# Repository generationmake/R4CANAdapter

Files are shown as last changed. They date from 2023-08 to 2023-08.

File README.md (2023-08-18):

# R4CANAdapter
CAN adapter for the Arduino UNO R4 minima and Arduino UNO R4 WiFi

<p align="center">
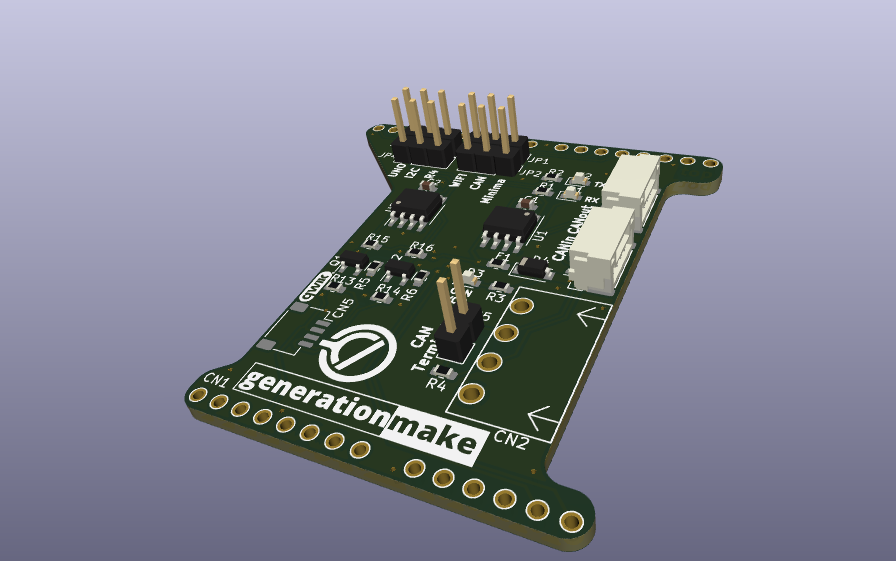
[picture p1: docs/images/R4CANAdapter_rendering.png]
  
</p>

## PCB
### Top
<p align="center">
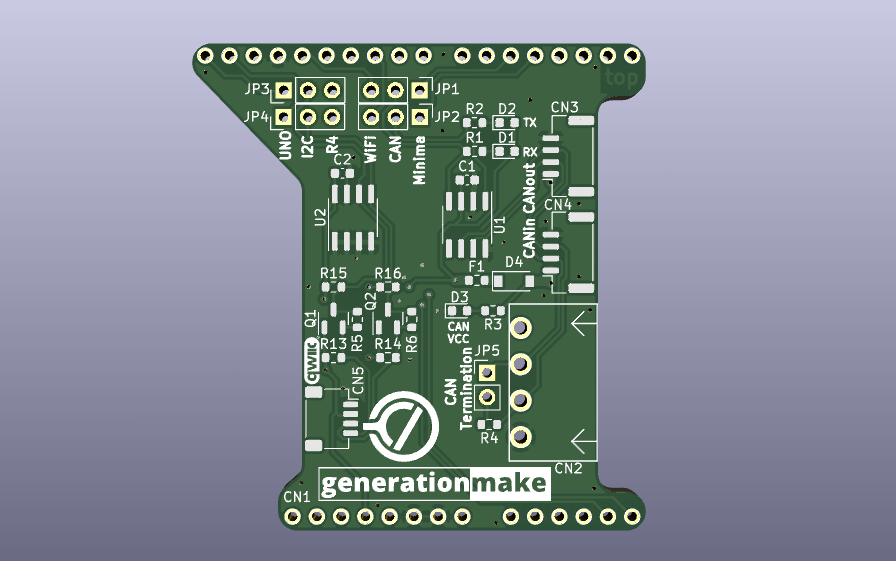
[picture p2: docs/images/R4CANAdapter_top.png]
  
</p>

### Bottom
<p align="center">
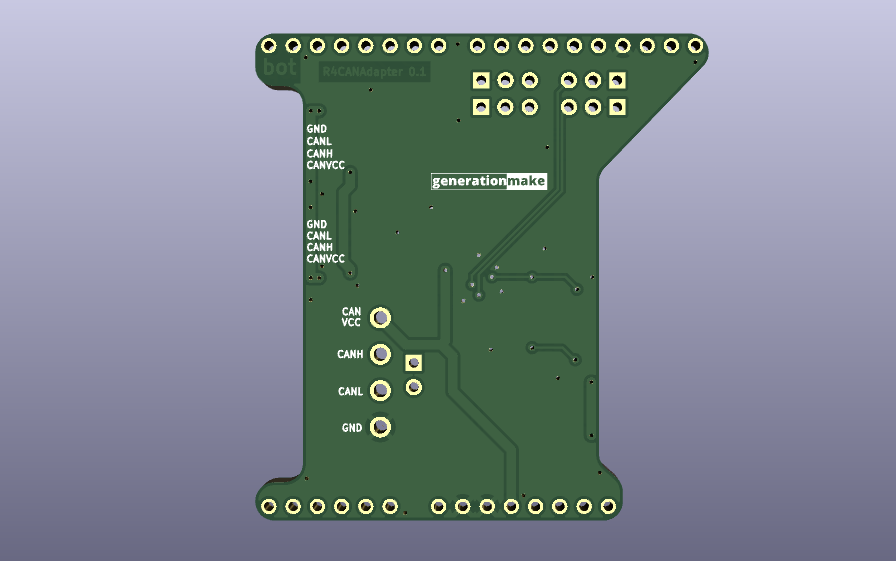
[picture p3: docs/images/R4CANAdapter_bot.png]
  
</p>

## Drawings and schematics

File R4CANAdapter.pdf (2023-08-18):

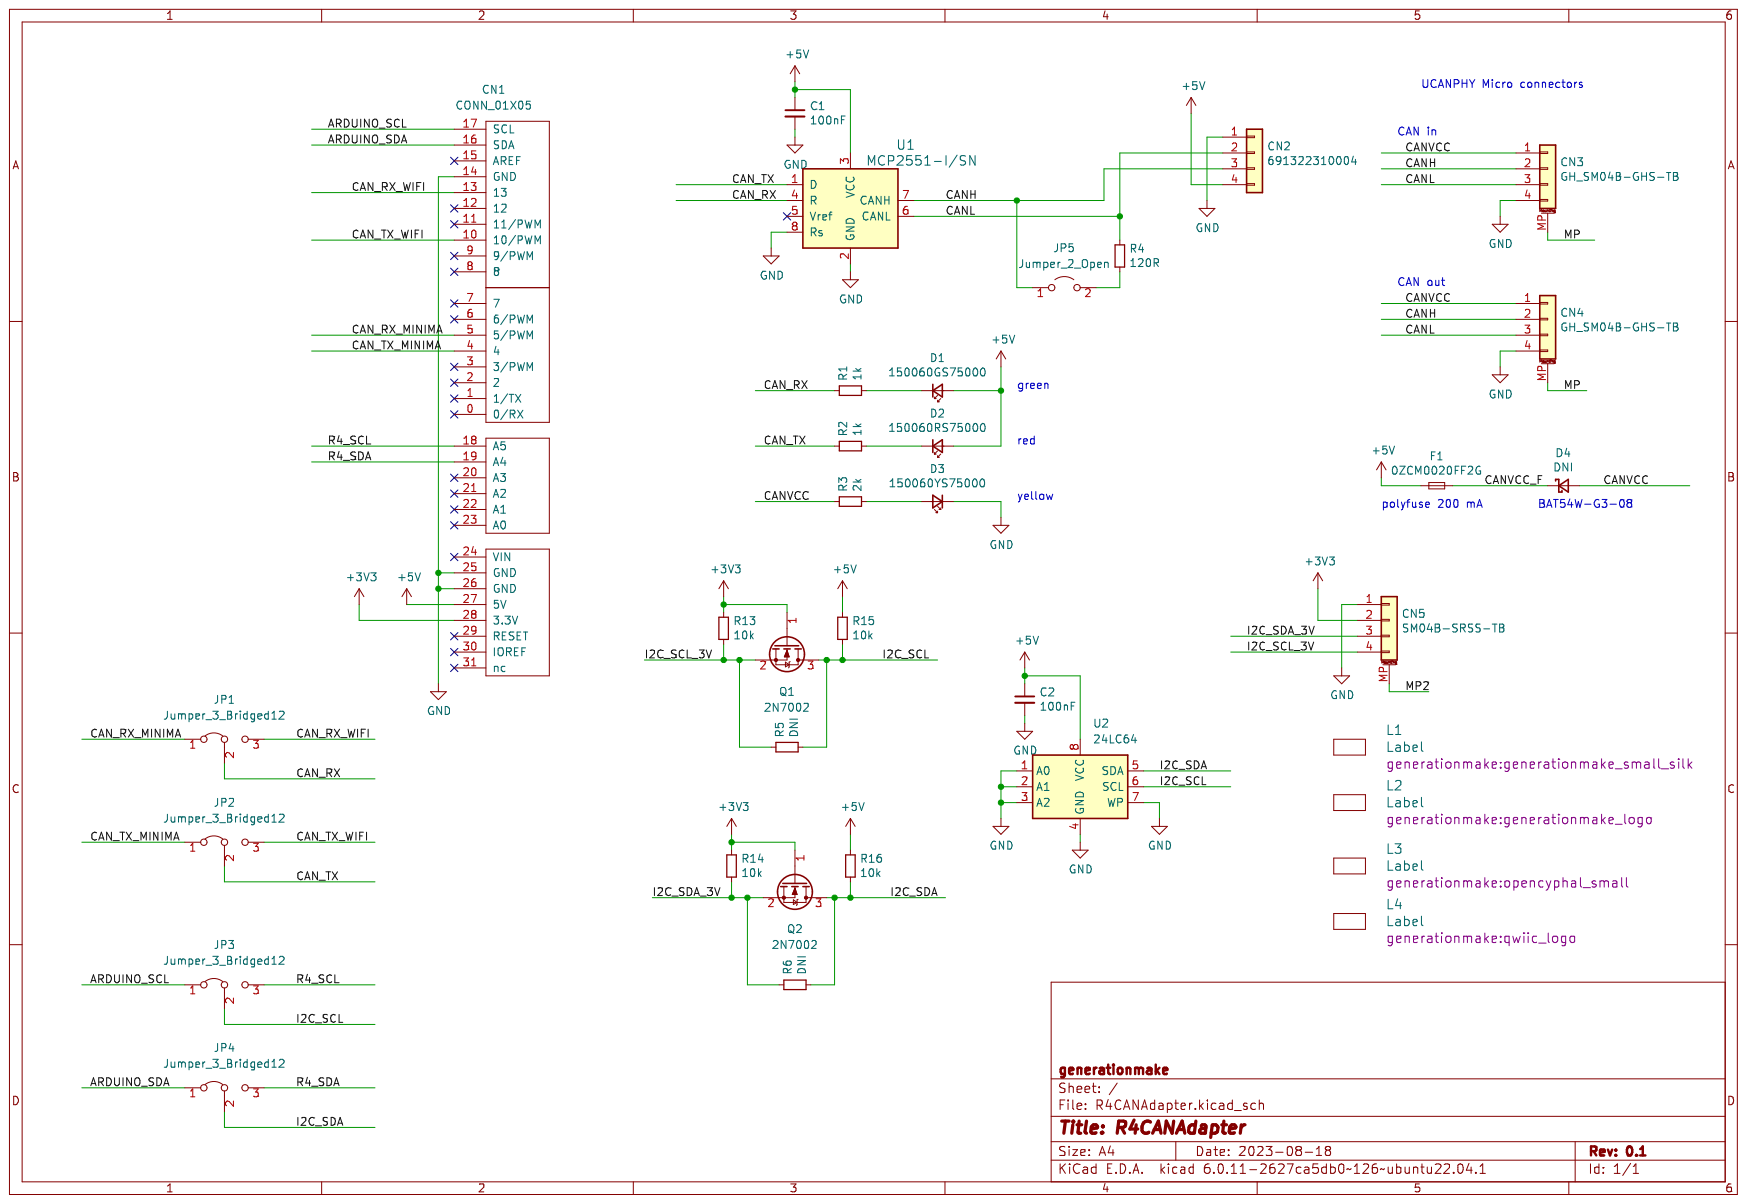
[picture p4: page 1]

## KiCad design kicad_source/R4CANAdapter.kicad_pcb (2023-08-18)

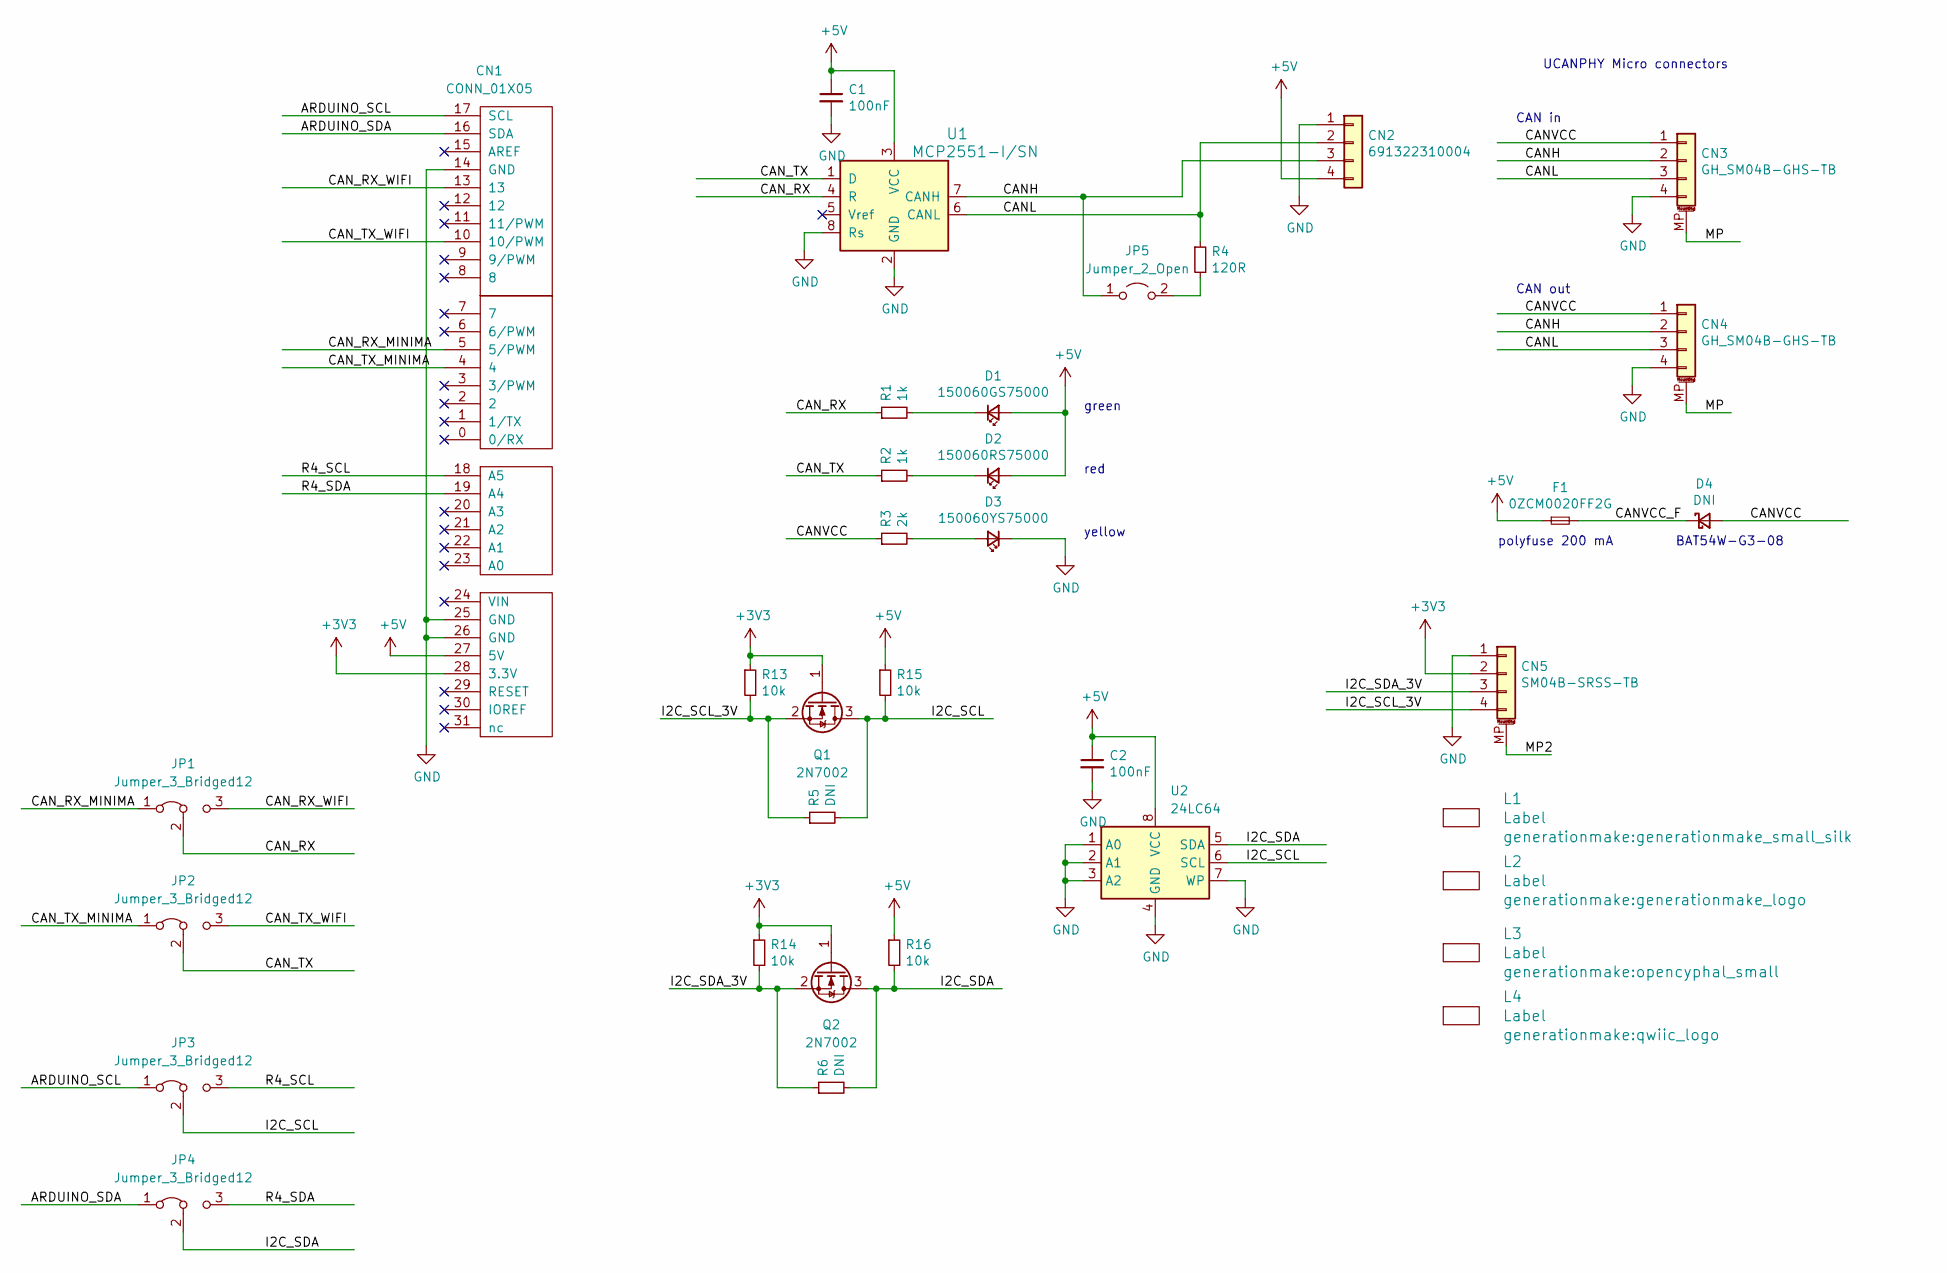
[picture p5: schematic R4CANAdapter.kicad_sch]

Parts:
C1, C2: 100nF; C_0603_1608Metric
CN1: CONN_01X05; ARDUINO
CN2: 691322310004; WR-TBL_691322310004
CN3, CN4: GH_SM04B-GHS-TB; JST_GH_SM04B-GHS-TB_1x04-1MP_P1.25mm_Horizontal
CN5: SM04B-SRSS-TB; JST_SH_SM04B-SRSS-TB_1x04-1MP_P1.00mm_Horizontal
D1: 150060GS75000; LED_0603_1608Metric
D2: 150060RS75000; LED_0603_1608Metric
D3: 150060YS75000; LED_0603_1608Metric
D4: DNI; D_SOD-123
F1: 0ZCM0020FF2G; R_0603_1608Metric
JP1, JP2, JP3, JP4: Jumper_3_Bridged12; PinHeader_1x03_P2.54mm_Vertical
JP5: Jumper_2_Open; PinHeader_1x02_P2.54mm_Vertical
L1: Label; generationmake_small_silk
L2: Label; generationmake_logo
L3: Label; opencyphal_small
L4: Label; qwiic_logo
Q1, Q2: 2N7002; SOT-23
R1, R2: 1k; R_0603_1608Metric
R3: 2k; R_0603_1608Metric
R4: 120R; R_0603_1608Metric
R5, R6: DNI; R_0603_1608Metric
R13, R14, R15, R16: 10k; R_0603_1608Metric
U1: MCP2551-I/SN; SOIC-8_3.9x4.9mm_P1.27mm
U2: 24LC64; SOIC-8_3.9x4.9mm_P1.27mm

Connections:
+3V3: CN1.28 (3.3V), CN5.2, Q1.1 (G), Q2.1 (G), R13.1, R14.1
+5V: C1.1, C2.1, CN1.27 (5V), CN2.4, D1.2 (A), D2.2 (A), F1.1, R15.1, R16.1, U1.3 (VCC), U2.8 (VCC)
/ARDUINO_SCL: CN1.17 (SCL), JP3.1 (A)
/ARDUINO_SDA: CN1.16 (SDA), JP4.1 (A)
/CANH: CN2.3, CN3.2, CN4.2, JP5.1 (A), U1.7 (CANH)
/CANL: CN2.2, CN3.3, CN4.3, R4.1, U1.6 (CANL)
/CANVCC: CN3.1, CN4.1, D4.2 (A), R3.1
/CANVCC_F: D4.1 (K), F1.2
/CAN_RX: JP1.2 (C), R1.1, U1.4 (R)
/CAN_RX_MINIMA: CN1.5 (5/PWM), JP1.1 (A)
/CAN_RX_WIFI: CN1.13, JP1.3 (B)
/CAN_TX: JP2.2 (C), R2.1, U1.1 (D)
/CAN_TX_MINIMA: CN1.4, JP2.1 (A)
/CAN_TX_WIFI: CN1.10 (10/PWM), JP2.3 (B)
/I2C_SCL: JP3.2 (C), Q1.3 (D), R5.2, R15.2, U2.6 (SCL)
/I2C_SCL_3V: CN5.4, Q1.2 (S), R5.1, R13.2
/I2C_SDA: JP4.2 (C), Q2.3 (D), R6.2, R16.2, U2.5 (SDA)
/I2C_SDA_3V: CN5.3, Q2.2 (S), R6.1, R14.2
/MP: CN3.MP (MountPin), CN4.MP (MountPin)
/MP2: CN5.MP (MountPin)
/R4_SCL: CN1.18 (A5), JP3.3 (B)
/R4_SDA: CN1.19 (A4), JP4.3 (B)
GND: C1.2, C2.2, CN1.14 (GND), CN1.25 (GND), CN1.26 (GND), CN2.1, CN3.4, CN4.4, CN5.1, D3.1 (K), U1.2 (GND), U1.8 (Rs), U2.1 (A0), U2.2 (A1), U2.3 (A2), U2.4 (GND), U2.7 (WP)
unnamed: D1.1 (K), R1.2
unnamed: D2.1 (K), R2.2
unnamed: D3.2 (A), R3.2
unnamed: JP5.2 (B), R4.2

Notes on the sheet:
CAN out
polyfuse 200 mA
CAN in
yellow
red
UCANPHY Micro connectors
BAT54W-G3-08
green

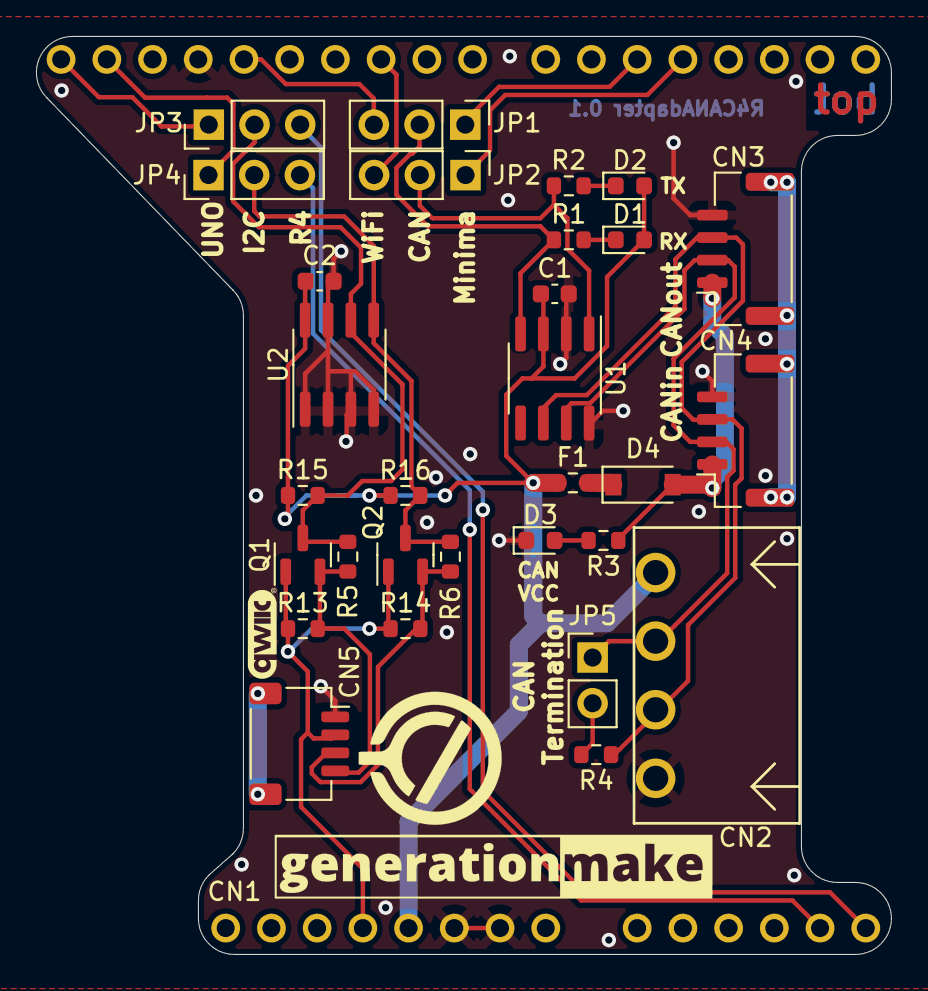
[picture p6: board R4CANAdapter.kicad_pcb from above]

Board: 2 copper layers, 47.5 x 51.0 mm, 35 parts (1 on the bottom side), 26 nets.

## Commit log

2023-08-12 added kicad project
    [R4CANAdapter.kicad_pcb, R4CANAdapter.kicad_sch]
2023-08-12 added Arduino Uno connector
    [R4CANAdapter.kicad_pcb, R4CANAdapter.kicad_sch]
2023-08-13 added I2C and eeprom
    [R4CANAdapter.kicad_pcb, R4CANAdapter.kicad_sch]
2023-08-14 beautified layout
    [R4CANAdapter.kicad_pcb]
2023-08-14 added pdf schematic
    [R4CANAdapter.kicad_sch]
2023-08-16 used real jumpers
    [R4CANAdapter.kicad_pcb, R4CANAdapter.kicad_sch]
2023-08-16 switched I2C eeprom and CAN driver to the 5V domain
    [R4CANAdapter.kicad_pcb, R4CANAdapter.kicad_sch]
2023-08-16 added bypass resistors for I2C circuit
    [R4CANAdapter.kicad_pcb, R4CANAdapter.kicad_sch]
2023-08-16 updated schematic pdf and image
    [R4CANAdapter.kicad_pcb]
2023-08-18 added jumper for CAN termination
    [R4CANAdapter.kicad_pcb, R4CANAdapter.kicad_sch]
2023-08-18 added some labels, beautified layout, made DRC
    [R4CANAdapter.kicad_pcb, R4CANAdapter.kicad_sch]
2023-08-18 updated schematic pdf
    [R4CANAdapter.kicad_sch]
2023-08-18 updated images
    [R4CANAdapter.kicad_pcb, R4CANAdapter.kicad_sch]
